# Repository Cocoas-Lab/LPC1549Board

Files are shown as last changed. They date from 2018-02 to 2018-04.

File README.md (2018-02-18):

# LPC1549 Develpment Board  

小型で安価なLPCボードの開発を目指しています  

## 機能
* USBからのバスパワー給電に対応
* 保護ICによるUSB短絡保護
* COMPortを介した書き込みに対応し, 別途書き込み機が不要 
* 5[V], 3.3[V]の2レベル電源出力 
* 22本の独立したGPIO
* 3個のオンチップLED
* 1個のユーザーボタン
* AD変換用に2.5[V]リファレンスを搭載

## イメージ
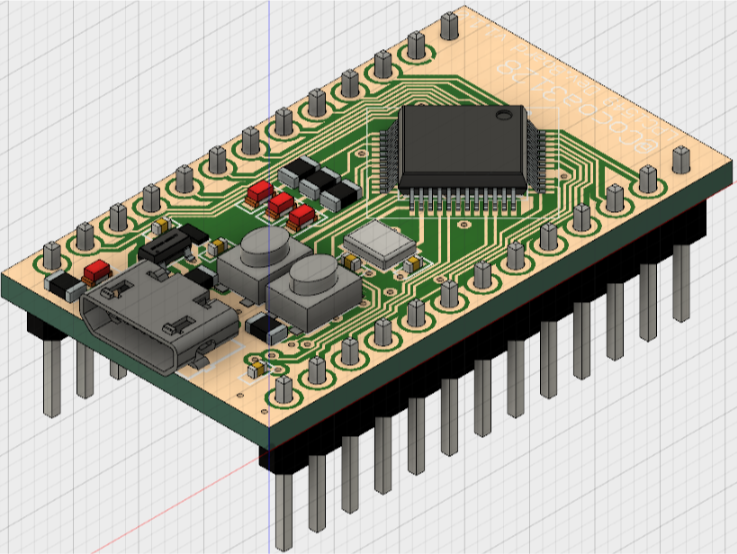
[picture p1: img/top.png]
top_view
  
上から見た画像  
  
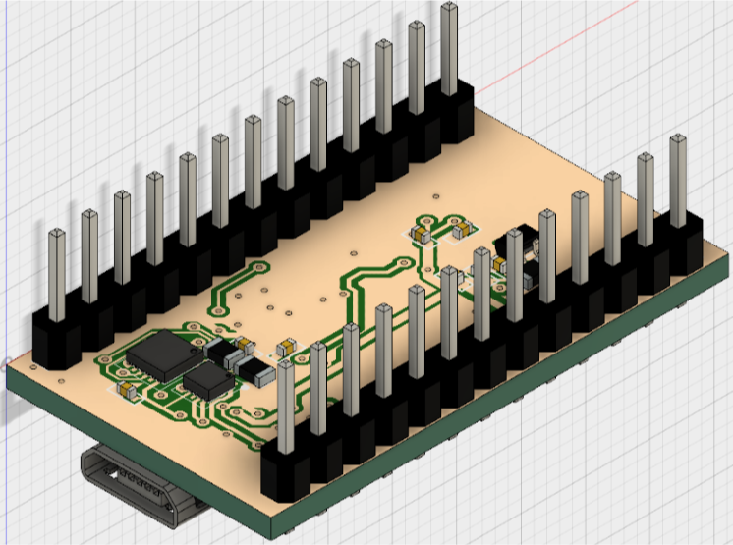
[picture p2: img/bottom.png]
bottom_view
  
下から見た画像

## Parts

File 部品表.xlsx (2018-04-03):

名称 | メーカー品番 | 値 | 規格 | 単価 | 個数 | 小計 | URL | 補足
チップ抵抗 | 311-330JRCT-ND | 330 | 1005 | 11 | 4 | 44 | https://www.digikey.jp/products/ja?keywords=311-330JRCT-ND
チップ抵抗 | RC0402JR-0710KL | 10k | 1005 | 11 | 5 | 55 | https://www.digikey.jp/products/ja?keywords=311-10KJRCT-ND
チップコンデンサ | GRM1555C1H100RA01D | 10p | 1005 | 12 | 2 | 24 | https://www.digikey.jp/product-detail/ja/murata-electronics-north-america/GRM1555C1H100RA01D/490-11374-1-ND/5333214
チップコンデンサ | GRM155R71A104KA01J | 0.1u | 1005 | 12 | 8 | 96 | https://www.digikey.jp/product-detail/ja/murata-electronics-north-america/GRM155R71A104KA01J/490-6322-1-ND/3845519
チップLED | LTST-C190KRKT | 赤 | 1608 | 32 | 1 | 32 | https://www.digikey.jp/product-detail/ja/lite-on-inc/LTST-C190KRKT/160-1436-1-ND/386816
チップLED | LTST-C190KGKT | 緑 | 1608 | 32 | 1 | 32 | https://www.digikey.jp/product-detail/ja/lite-on-inc/LTST-C190KGKT/160-1435-1-ND/386814
チップLED | QBLP601-IW | 白 | 1608 | 47 | 1 | 47 | https://www.digikey.jp/product-detail/ja/qt-brightek-qtb/QBLP601-IW/1516-1057-1-ND/4814784
IC | TPD4S014DSQR | 2A | 10-SON | 202 | 1 | 202 | https://www.digikey.jp/product-detail/ja/texas-instruments/TPD4S014DSQR/296-29093-1-ND/2688396
microUSBコネクタ | ZX62-AB-5PA(31) |  | USBmicro-B | 98 | 1 | 98 | https://www.digikey.jp/product-detail/ja/hirose-electric-co-ltd/ZX62-AB-5PA-31/H125279CT-ND/5994741
リニアレギュレータ | MCP1700T-3302E/TT | 3.3V,250mA | SOT23-3 | 46 | 1 | 46 | https://www.digikey.jp/product-detail/ja/microchip-technology/MCP1700T-3302E-TT/MCP1700T3302ETTCT-ND/652677
基準電圧 | ADR5041BKSZ-REEL7 | 2.5V | SC70 | 134 | 1 | 134 | https://www.digikey.jp/product-detail/ja/analog-devices-inc/ADR5041BKSZ-REEL7/ADR5041BKSZ-REEL7CT-ND/1523070
ダイオード | SDM2U40CSP-7B | 40V,2A | 1608 | 55 | 2 | 110 | https://www.digikey.jp/product-detail/ja/diodes-incorporated/SDM2U40CSP-7B/SDM2U40CSP-7BDICT-ND/6013037
発振子 | FA-238V 12.0000MB-K3 | 12.00MHz | 4-SMD | 135 | 1 | 135 | https://www.digikey.jp/product-detail/ja/epson/FA-238V-12.0000MB-K3/SER3682CT-ND/2403455
IC | LPC1549JBD48QL |  | 48-LQFP | 822 | 1 | 822 | https://www.digikey.jp/products/ja?keywords=LPC1549JBD48
スイッチ | SKRPACE010 |  |  | 40 | 1 | 40 | http://akizukidenshi.com/catalog/g/gP-06185/ | 5個入り(値段は2個換算)
ピンヘッダ | PH-1x40SG | 1x40 |  | 35 | 1 | 35 | http://akizukidenshi.com/catalog/g/gC-00167/
合計 |  |  |  |  |  | 1952

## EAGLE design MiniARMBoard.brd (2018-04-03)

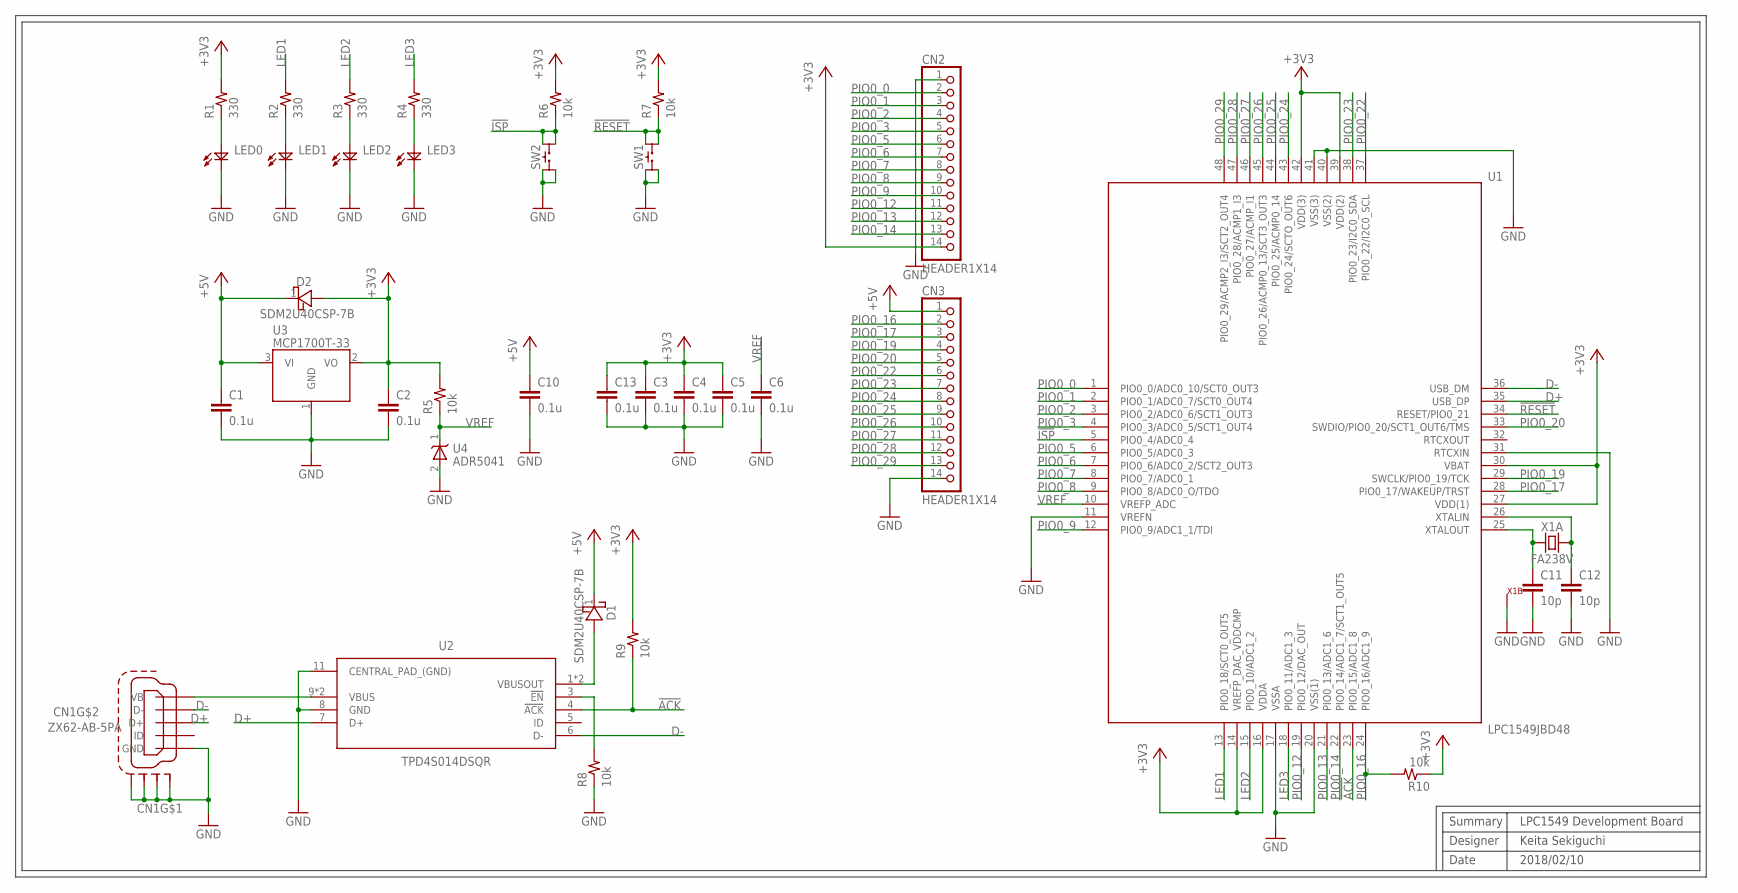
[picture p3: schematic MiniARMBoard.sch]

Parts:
C1, C2, C3, C4, C5, C6, C10, C13: 0.1u; C1005
C11, C12: 10p; C1005
CN1: ZX62-AB-5PA; J_USB_MICROAB_HIROSE_ZX62-AB-5PA
CN2, CN3: HEADER1X14; 1X14_ROUND
D1, D2: SDM2U40CSP-7B; X3-WLB1608-2
LED0, LED1, LED2, LED3: LED1608
R1, R2, R3, R4: 330; R1005
R5, R6, R7, R8, R9, R10: 10k; R1005
SW1, SW2: SKRP
U1: LPC1549JBD48; QFP48
U2: TPD4S014DSQR; SON40P200X200X80-11N
U3: MCP1700T-33; SOT23-3
U4: ADR5041; SC70-3
X1: FA238V; EPSON_FA238V

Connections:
!ACK: R9.1, U1.23 (PIO0_15/ADC1_8), U2.4 (!ACK)
!ISP: R6.1, SW2.B1, SW2.B2, U1.5 (PIO0_4/ADC0_4)
!RESET: R7.1, SW1.B1, SW1.B2, U1.34 (RESET/PIO0_21)
+3V3: C2.1, C3.1, C4.1, C5.1, C13.1, CN2.14, D2.2 (A), R1.2, R5.2, R6.2, R7.2, R9.2, R10.1, U1.14 (VREFP_DAC_VDDCMP), U1.16 (VDDA), U1.27 (VDD(1)), U1.30 (VBAT), U1.39 (VDD(2)), U1.42 (VDD(3)), U3.2 (VO)
+5V: C1.1, C10.1, CN3.1, D1.1 (K), D2.1 (K), U3.3 (VI)
D+: CN1.P$3 (D+), U1.35 (USB_DP), U2.7 (D+)
D-: CN1.P$2 (D-), U1.36 (USB_DM), U2.6 (D-)
GND: C1.2, C2.2, C3.2, C4.2, C5.2, C6.2, C10.2, C11.2, C12.2, C13.2, CN1.P$5 (GND), CN1.SHIELD1 (S1), CN1.SHIELD2 (S2), CN1.SHIELD3 (S3), CN1.SHIELD4 (S4), CN2.1, CN3.14, LED0.K, LED1.K, LED2.K, LED3.K, R8.1, SW1.A1, SW1.A2, SW2.A1, SW2.A2, U1.11 (VREFN), U1.17 (VSSA), U1.20 (VSS(1)), U1.31 (RTCXIN), U1.40 (VSS(2)), U1.41 (VSS(3)), U2.8 (GND), U2.11 (CENTRAL_PAD_(GND)), U3.1 (GND), U4.2 (A), X1.2 (1), X1.4 (1)
LED1: R2.2, U1.13 (PIO0_18/SCT0_OUT5)
LED2: R3.2, U1.15 (PIO0_10/ADC1_2)
LED3: R4.2, U1.18 (PIO0_11/ADC1_3)
unnamed: C11.1, U1.25 (XTALOUT), X1.1
unnamed: C12.1, U1.26 (XTALIN), X1.3
unnamed: D1.2 (A), U2.1 (VBUSOUT), U2.2 (VBUSOUT)
unnamed: R8.2, U2.3 (!EN)
unnamed: LED0.A, R1.1
unnamed: LED2.A, R3.1
unnamed: LED3.A, R4.1
unnamed: LED1.A, R2.1
unnamed: CN1.P$1 (VB), U2.9 (VBUS), U2.10 (VBUS)
PIO0_0: CN2.2, U1.1 (PIO0_0/ADC0_10/SCT0_OUT3)
PIO0_1: CN2.3, U1.2 (PIO0_1/ADC0_7/SCT0_OUT4)
PIO0_2: CN2.4, U1.3 (PIO0_2/ADC0_6/SCT1_OUT3)
PIO0_3: CN2.5, U1.4 (PIO0_3/ADC0_5/SCT1_OUT4)
PIO0_5: CN2.6, U1.6 (PIO0_5/ADC0_3)
PIO0_6: CN2.7, U1.7 (PIO0_6/ADC0_2/SCT2_OUT3)
PIO0_7: CN2.8, U1.8 (PIO0_7/ADC0_1)
PIO0_8: CN2.9, U1.9 (PIO0_8/ADC0_O/TDO)
PIO0_9: CN2.10, U1.12 (PIO0_9/ADC1_1/TDI)
PIO0_12: CN2.11, U1.19 (PIO0_12/DAC_OUT)
PIO0_13: CN2.12, U1.21 (PIO0_13/ADC1_6)
PIO0_14: CN2.13, U1.22 (PIO0_14/ADC1_7/SCT1_OUT5)
PIO0_16: CN3.2, R10.2, U1.24 (PIO0_16/ADC1_9)
PIO0_17: CN3.3, U1.28 (PIO0_17/WAKEUP/TRST)
PIO0_19: CN3.4, U1.29 (SWCLK/PIO0_19/TCK)
PIO0_20: CN3.5, U1.33 (SWDIO/PIO0_20/SCT1_OUT6/TMS)
PIO0_22: CN3.6, U1.37 (PIO0_22/I2C0_SCL)
PIO0_23: CN3.7, U1.38 (PIO0_23/I2C0_SDA)
PIO0_24: CN3.8, U1.43 (PIO0_24/SCTO_OUT6)
PIO0_25: CN3.9, U1.44 (PIO0_25/ACMP0_14)
PIO0_26: CN3.10, U1.45 (PIO0_26/ACMP0_13/SCT3_OUT3)
PIO0_27: CN3.11, U1.46 (PIO0_27/ACMP_I1)
PIO0_28: CN3.12, U1.47 (PIO0_28/ACMP1_I3)
PIO0_29: CN3.13, U1.48 (PIO0_29/ACMP2_I3/SCT2_OUT4)
VREF: C6.1, R5.1, U1.10 (VREFP_ADC), U4.1 (K)

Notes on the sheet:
Keita Sekiguchi
Summary
LPC1549 Development Board
Designer
Date
2018/02/10

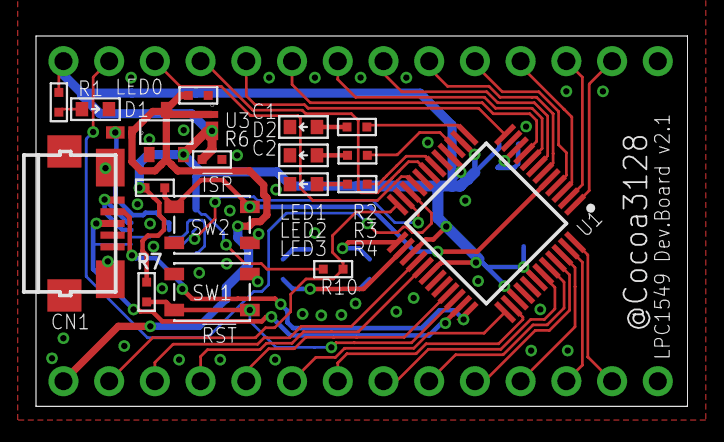
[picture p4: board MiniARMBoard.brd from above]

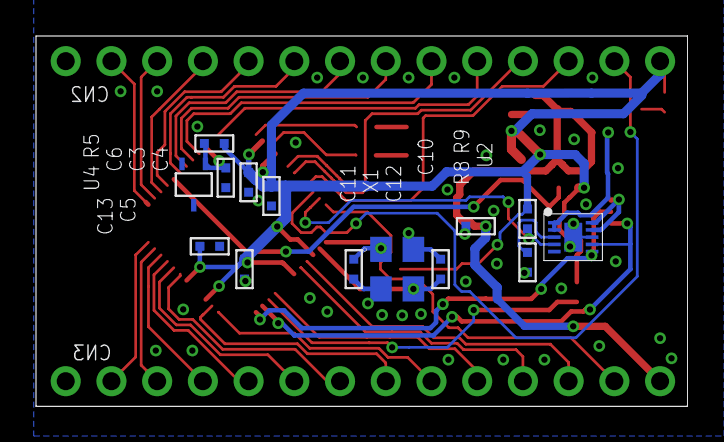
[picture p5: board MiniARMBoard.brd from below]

Board: 2 copper layers, 36.2 x 20.6 mm, 36 parts (14 on the bottom side), 45 nets.

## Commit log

2017-12-23 LPCボードの第一回発注
    [MiniARMBoard.brd, MiniARMBoard.sch, 部品表.xlsx]
2017-12-27 elecrowの指示による訂正
    [MiniARMBoard.brd, 部品表.xlsx]
2018-01-07 gitignoreの更新
2018-01-07 パーツ変更
    USBの保護をRFからICに
    シリアル変換ICをFT234XDに
    [MiniARMBoard.brd, MiniARMBoard.sch]
2018-01-23 集積化を進めた
    [MiniARMBoard.brd]
2018-02-10 シルクの調整を行なった
    [MiniARMBoard.brd]
2018-02-10 ICの名前を'IC*'から'U*'に変更
    [MiniARMBoard.brd, MiniARMBoard.sch]
2018-02-10 FusionSincで変更されたやつ
    [MiniARMBoard.brd]
2018-02-10 発注時のgerver
2018-02-18 部品表の更新
    [部品表.xlsx]
2018-02-18 readme.mdを追加
2018-02-18 キャプションの改行
2018-03-07 回路図の見た目を整えてみた
    [MiniARMBoard.brd, MiniARMBoard.sch]
2018-04-03 [fix]usb-dfu仕様に変更
    [MiniARMBoard.brd, MiniARMBoard.sch, 部品表.xlsx]
2018-04-03 [fix]未保存分
    [MiniARMBoard.brd, MiniARMBoard.sch]
